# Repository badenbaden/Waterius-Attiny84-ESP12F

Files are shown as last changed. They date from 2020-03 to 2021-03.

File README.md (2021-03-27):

### Альтернативная схемотехника автономного устройства для передачи показаний воды по Wi-Fi - Ватериус.

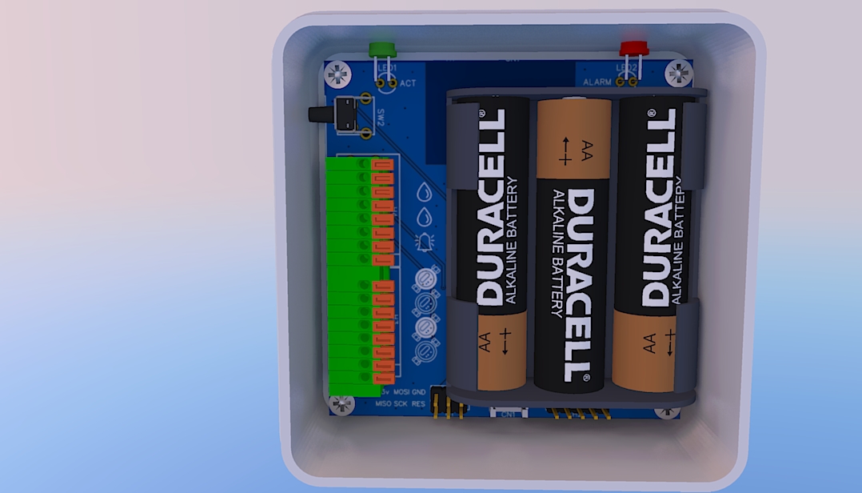
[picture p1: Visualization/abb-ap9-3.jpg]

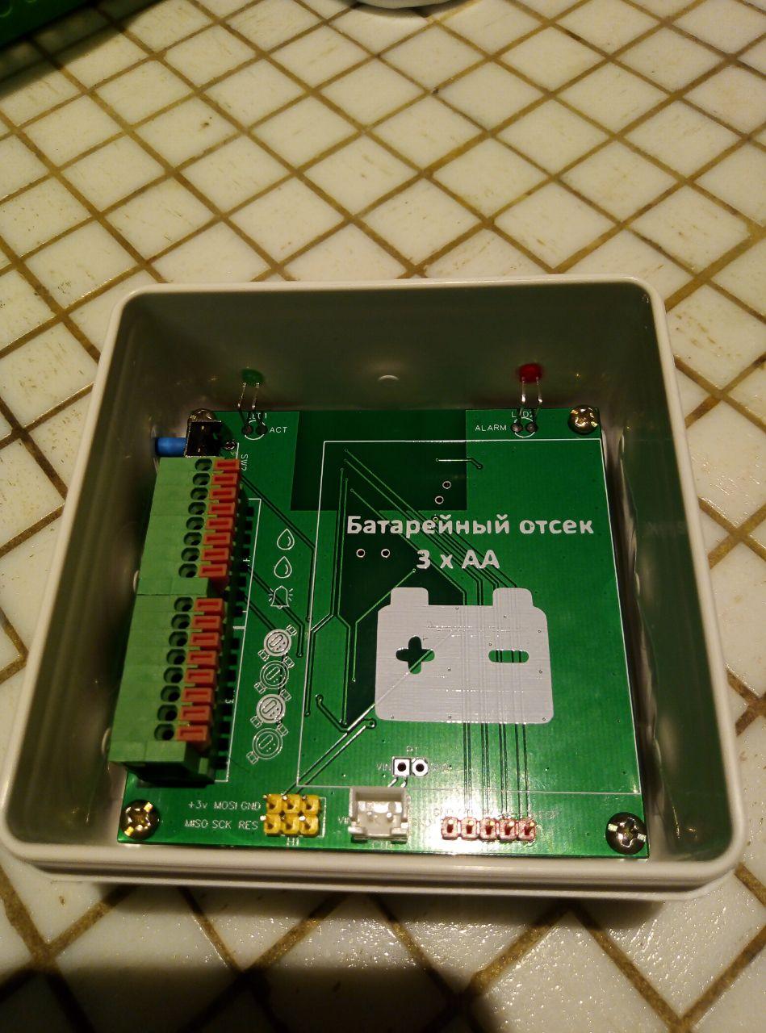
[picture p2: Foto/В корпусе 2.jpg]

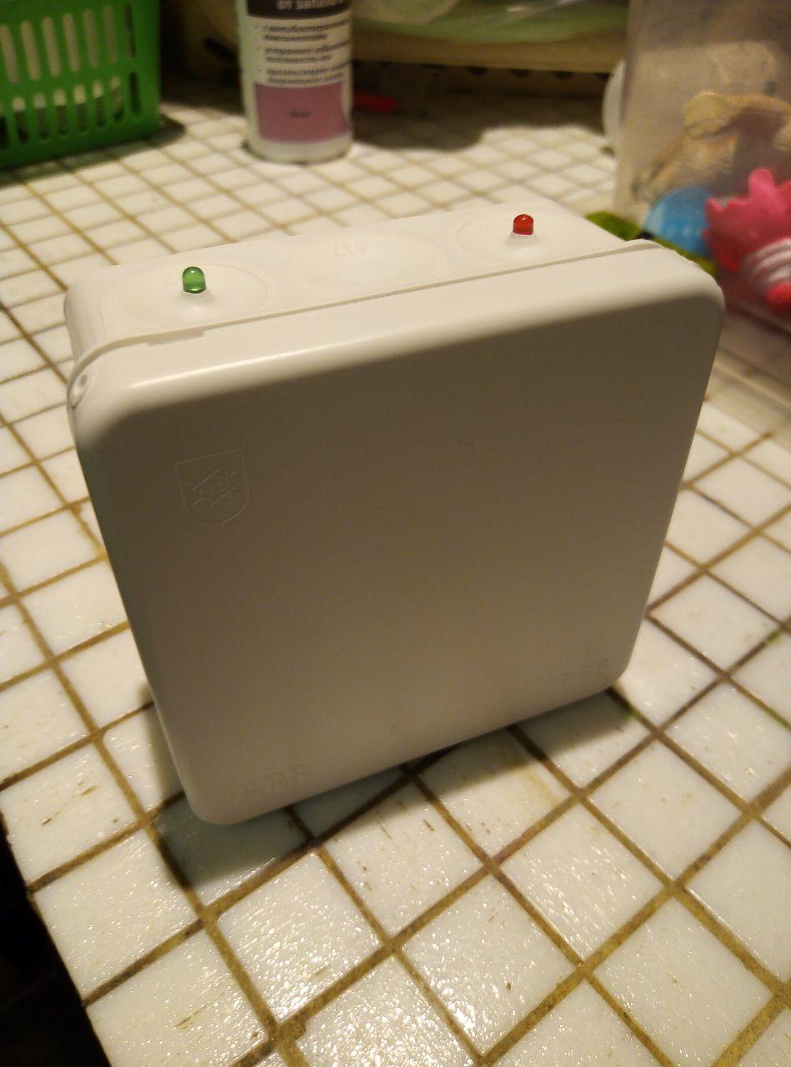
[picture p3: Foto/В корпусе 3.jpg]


[Оригинальная версия, взятая за основу](https://github.com/dontsovcmc/waterius/)

[Обсуждение данной версии, испытания, симуляции и т.д.](https://github.com/dontsovcmc/waterius/issues/128)

### Текущий статус:
- Бета версия.
- Устройство [изготовлено](https://github.com/badenbaden/Waterius-Attiny84-ESP12F/tree/master/Foto), пишется прошивка.
- На текущий момент работают 4 счетчика, 2 датчика протечки. Отображение в облаке Ватериус только 2х счетчиков, датчики протечки также не отображаются.
- Тестовые прошивки: [Вторая Бета](https://github.com/badenbaden/Waterius-Attiny84-ESP12F/tree/master/Firmware/SecondBeta)
[Первая Бета](https://github.com/badenbaden/Waterius-Attiny84-ESP12F/tree/master/Firmware/FirstBeta)
=======
- На текущий момент работают 4 счетчика, 2 датчика протечки, отправляет оповещение при протечке (пока только одного канала). Отображение в облаке Ватериус только 2х счетчиков.
- Тестовые прошивки [тут](https://github.com/badenbaden/Waterius-Attiny84-ESP12F/tree/master/Firmware/FirstBeta).

### Планируемые возможности:
- 4 счётчика воды (вам не нужно знать, какого типа выход: "сухой контакт" или "НАМУР")
- передача по Wi-Fi раз в сутки
- питание 3 АА батарейки (~4 года работы)
- не нужно знать, сколько литров на импульс (Ватериус сам определит 1 или 10л/имп)
- корпус с защитой от пыли и воды (IP65) 
- контроль напряжения батареи
- 2 независимых канала для датчиков протечки (для лучшего понимания зоны возможной протечки)
- индикация протечки светодиодом, передача тревожного сообщения на сайт, mqtt
- отдельный вывод сигнала протечки (для передачи на внешние исполнители или информеры)
- вывод под датчик температуры (подключен к есп8266, т.е. контроль возможен не чаще включения WiFi)
- полное отключение есп8266 от питания, для продление жизни батарей
- использование есп8266 версии 12E, 12F или 12S
- выведены на плате GPIO9, GPIO10, GPIO12, GPIO14
- отдельные порты для прошивки и мониторинга attiny и esp
- может еще что забыл))

### Прошивка:
С прошивкой обещал помочь автор оригинального ватериуса - @dontsovcmc

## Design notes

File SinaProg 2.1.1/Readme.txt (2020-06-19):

SinaProg 2.1 - AVRDUDE-GUI with AVR Fuse Calculator

* You can edit the file ".\data\Fuses.txt", to add your comments for writing fuse bits.

* If you have any problem with parallel port on Windows NT/2K/XP you must execute "install_giveio.bat" from ".\data\Giveio.zip".

* If you have any problem with USBasp programmer you must update the windows driver from ".\data\USBasp Driver 0.1.12.1.zip".

* For using SinaProg with Wine in Linux, rename "Port.txt" to "Port.win" and then rename "Port.lnx" to "Port.txt"

sn.ghaderi@yahoo.com

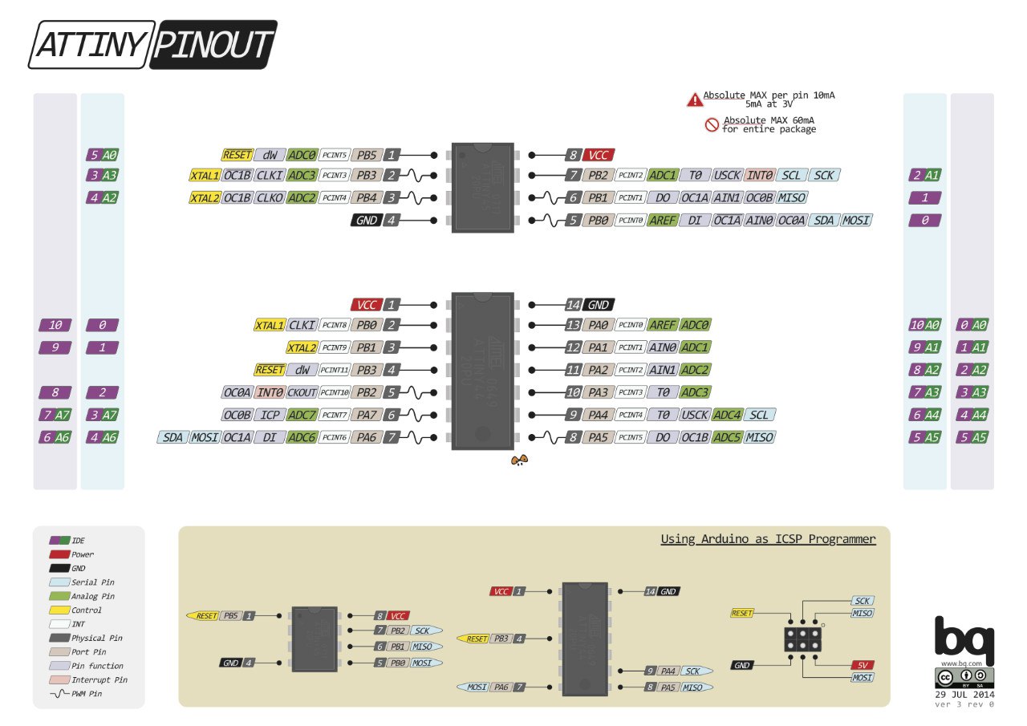
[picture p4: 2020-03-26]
Datasheet/attiny84 pinout.jpg

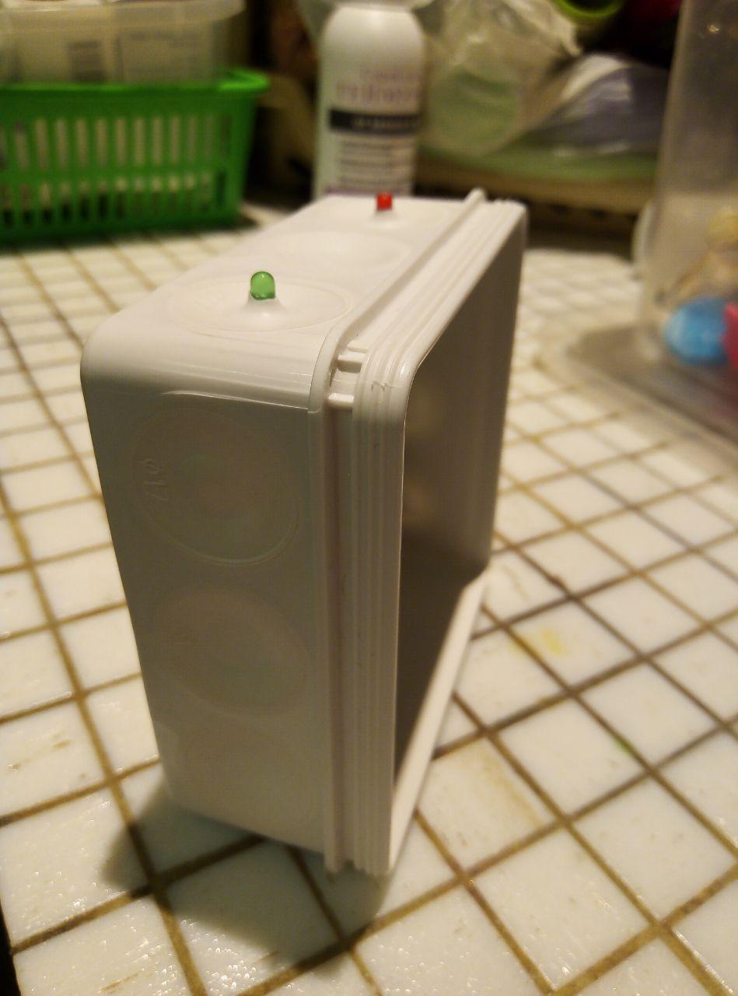
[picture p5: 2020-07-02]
Foto/В корпусе 4.jpg

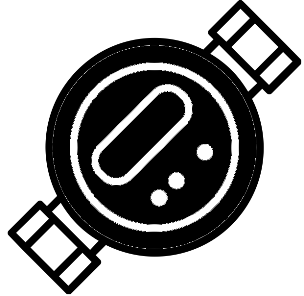
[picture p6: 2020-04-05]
Others/холодная.png

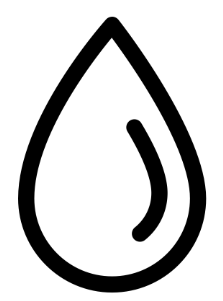
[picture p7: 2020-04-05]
Others/капля.png

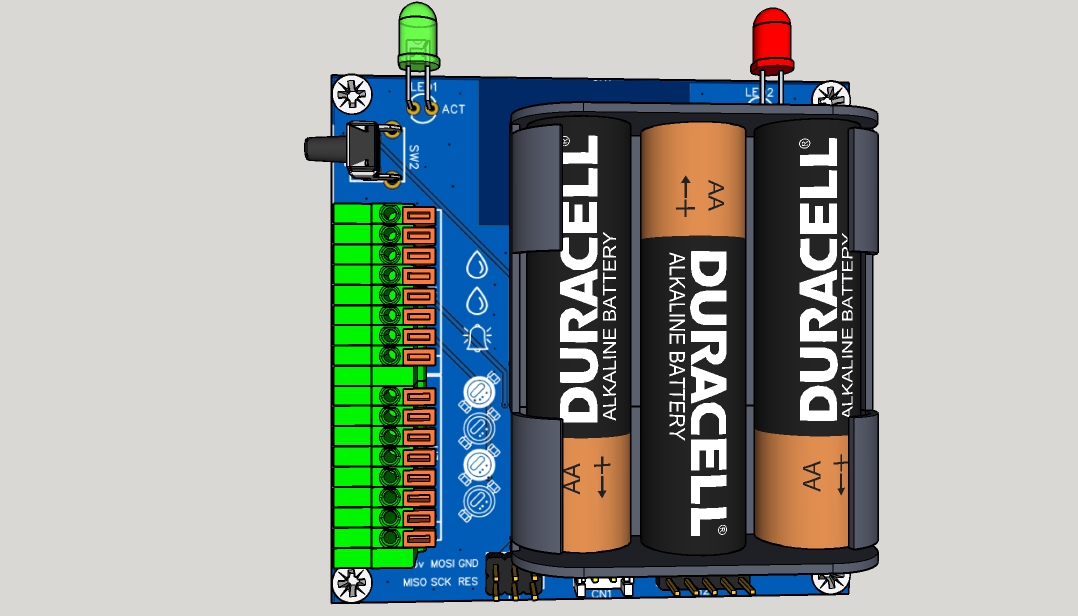
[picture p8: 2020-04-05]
Visualization/рендер-верх2.jpg

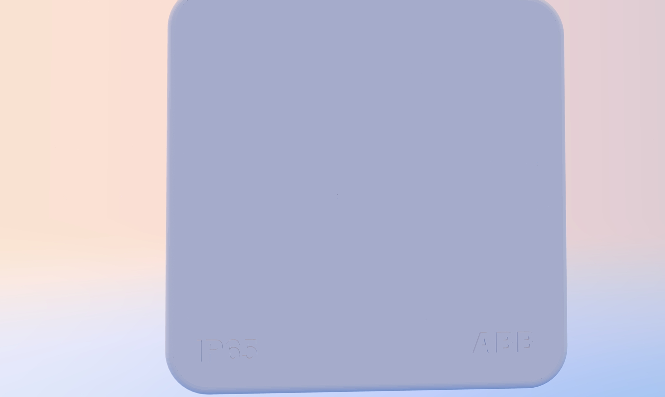
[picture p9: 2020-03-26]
Visualization/abb-ap9-2.jpg

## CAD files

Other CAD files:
Others/0805.skp
Others/1X05.skp
Others/2X03.skp
Others/B2B-EH-A.skp
Others/ESP8266.skp
Others/battery+AA.skp
Others/soic-14.skp
Others/sot-23.skp

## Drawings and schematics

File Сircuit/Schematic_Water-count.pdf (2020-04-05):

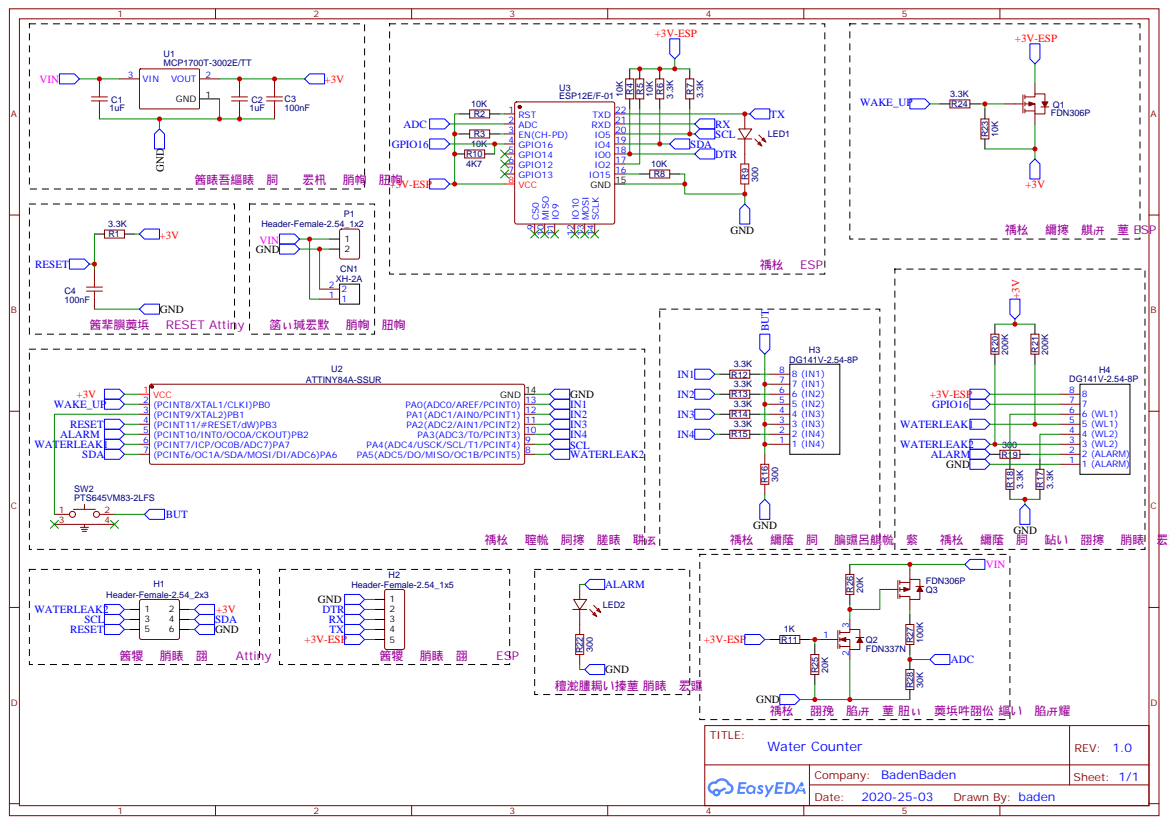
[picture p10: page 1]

䇴䁃吾䌔䁃з䏤㉃т䍔㭄쀀 䏴㡄␰䏔㡄

GND
䄔㭃 䎄㝃쐵䐄㕃퐸䓰 䏔ぃ䓴㙃吽䎄伀 䌔い␰䐄㕃耀

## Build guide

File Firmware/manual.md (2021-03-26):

При использовании usb-ttl (для esp-01) для прошивки есп:

|----|
|1234|
|5678|	   Желтым разъемом вверх. ЮСБ разъем вниз
|    |
|____|
  ||
  
1 - +3v 
4 - TX
5 - RX
8 - GND

DTR перед включением замкнуть на GND.
 
После подачи питания, при первичной настройке, устройство создаст точку для подключения (зажимать при вставке батарей теперь не нужно)

Устарело!!!После прошивки, перед подачей питания зажать кнопку и вставить батарейку, через 5-7 секунд отпустить кнопку. Должна включиться точка доступа на приборе, необходимая для настройки.

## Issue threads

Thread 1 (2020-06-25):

Датчики протечки: алгоритм

dontsovcmc, 2020-06-25:
Предлагаю обсудить, как должен работать алгоритм датчиков протечки.

Вопросы:
1. Читать как дискретный или аналоговый вход?
дискретный:
- нельзя будет обрыв детектировать
+ меньше потребление
+ уже так сделал @OloloevReal
аналоговый:
- больше потребление (хотя раз в 15 сек не сильно повлияет)
надо проверить, что компаратор показывает при воде

2.  Как часто опрашивать вход?
предлагаю раз в ~30 сек

3. Что делать при детектировании?
Будим ESP, отправляем данные.
а. Нужно ли убеждаться, что данные отправлены?
б. Что делать ,если ошибка отправки данных?
в. Как сбросить тревогу? Иначе он будет отправлять данные бесконечно, пока вода на датчике.

4. Как должен работать пин "тревога"?

5. Нужно ли статус датчика показывать в веб интерфейсе?

badenbaden, 2020-07-16:
Думаю нужно делать как аналоговый вход, опрос раз в 10 секунд (для начала). Детектировать обрыв нужно, иначе нет от датчика нет смысла. Вот только как правильно сделать это детектирование. Сейчас выводы датчика подключены через резисторы к + и - соответственно. При стандартном подключении без контроля обрыва на входе АЦП будет 1023, при намокании значение будет падать, на сколько - проверим опытным путем.
При изменении значения (протечки) включаем порт ALARM. При возврате значения в норму выключать порт ALARM. **Это главное, что нужно сделать.**  Уведомление на разные сервисы это хорошо, но он должен дать команду на закрытие кранов/зуммер/лампа/сигнализация, а уже потом стучаться до пользователя.

Будить есп надо, она должна отправить значения на сервер/mqtt/Blynk. Проверка отправки желательна, но это не первоочередная задача, а вот если ошибка отправки - то повторять попытки пока не будет успешна. Думаю при протечке смысла экономить батарейки нет. Ну а после отправки сам сервис уже пусть связывается с пользователем.

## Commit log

2020-04-05 Каталогизировал информацию
    [0805.skp, 1X05.skp, 2X03.skp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]
2020-04-05 Добавил рендер
2020-06-19 Добавил программу прошивальщик и сами прошивки для тестовой версии
2020-06-19 Добавил фото и SinaProg
2020-06-19 Обновил описание
2020-07-02 Добавил фото корпуса и платы в корпусе
2020-07-02 Добавил фото
2020-07-02 Прошивка тини без лога
    Прошивка тини без лога, работают все 4 канала счетчиков
